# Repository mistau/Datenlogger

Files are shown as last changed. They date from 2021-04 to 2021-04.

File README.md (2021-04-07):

# Datenlogger
Flexible data logger working for many months on cheap AA batteries.

## Status
PCB back from fab, populated and tested. Extensive testroutines available in folder hwtest.
Unfortunatelly PCB rev 1.0 has two missing connections (i2c bus) which requires two ugly wires.
This is fixed in HW revision 1.1.
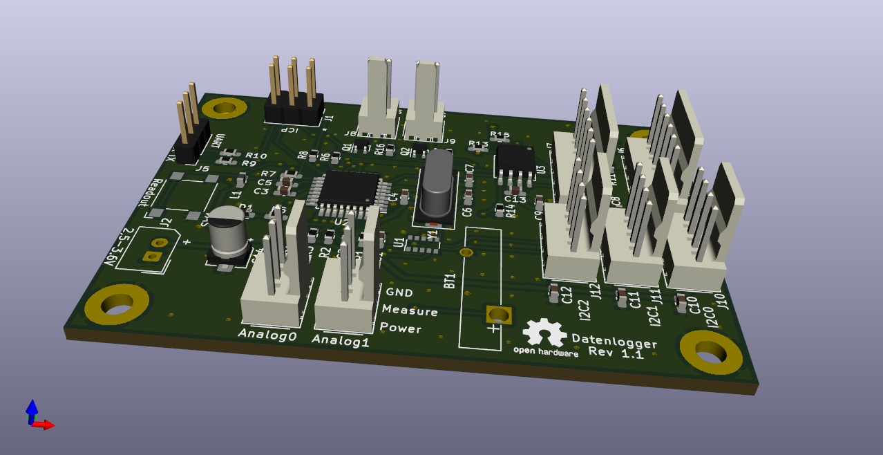
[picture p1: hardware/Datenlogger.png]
3D


## what's next
Application software for light sensor under development.

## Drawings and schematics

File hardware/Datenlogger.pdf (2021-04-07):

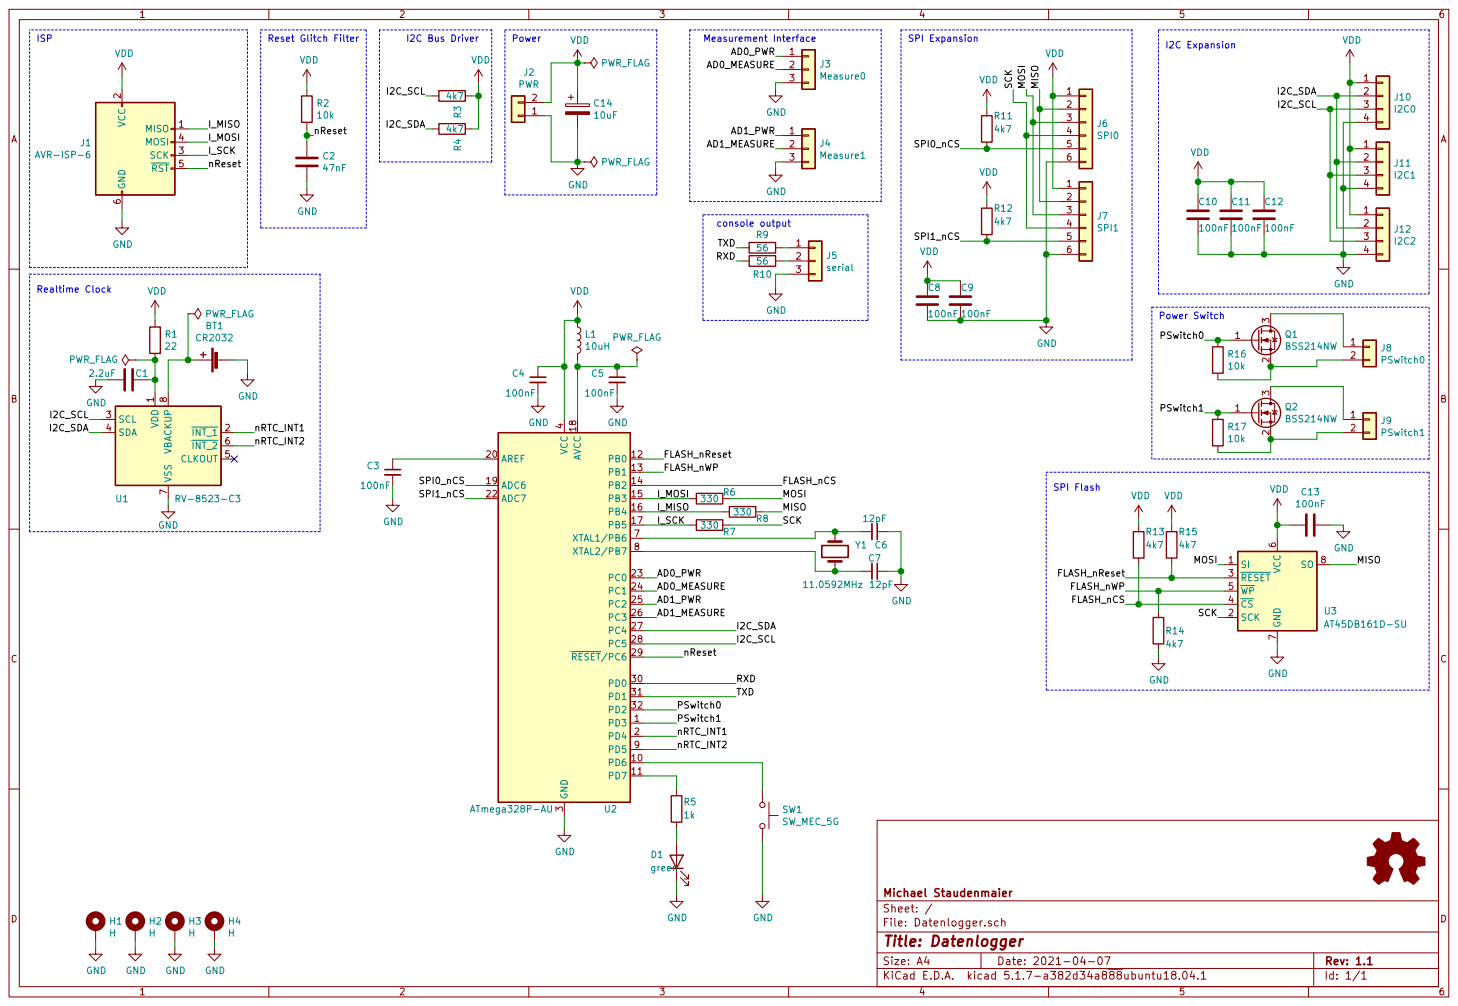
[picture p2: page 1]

2 SCK 3 MOSI 4 RST 5 GND

File: Datenlogger.sch Sheet: / Michael Staudenmaier

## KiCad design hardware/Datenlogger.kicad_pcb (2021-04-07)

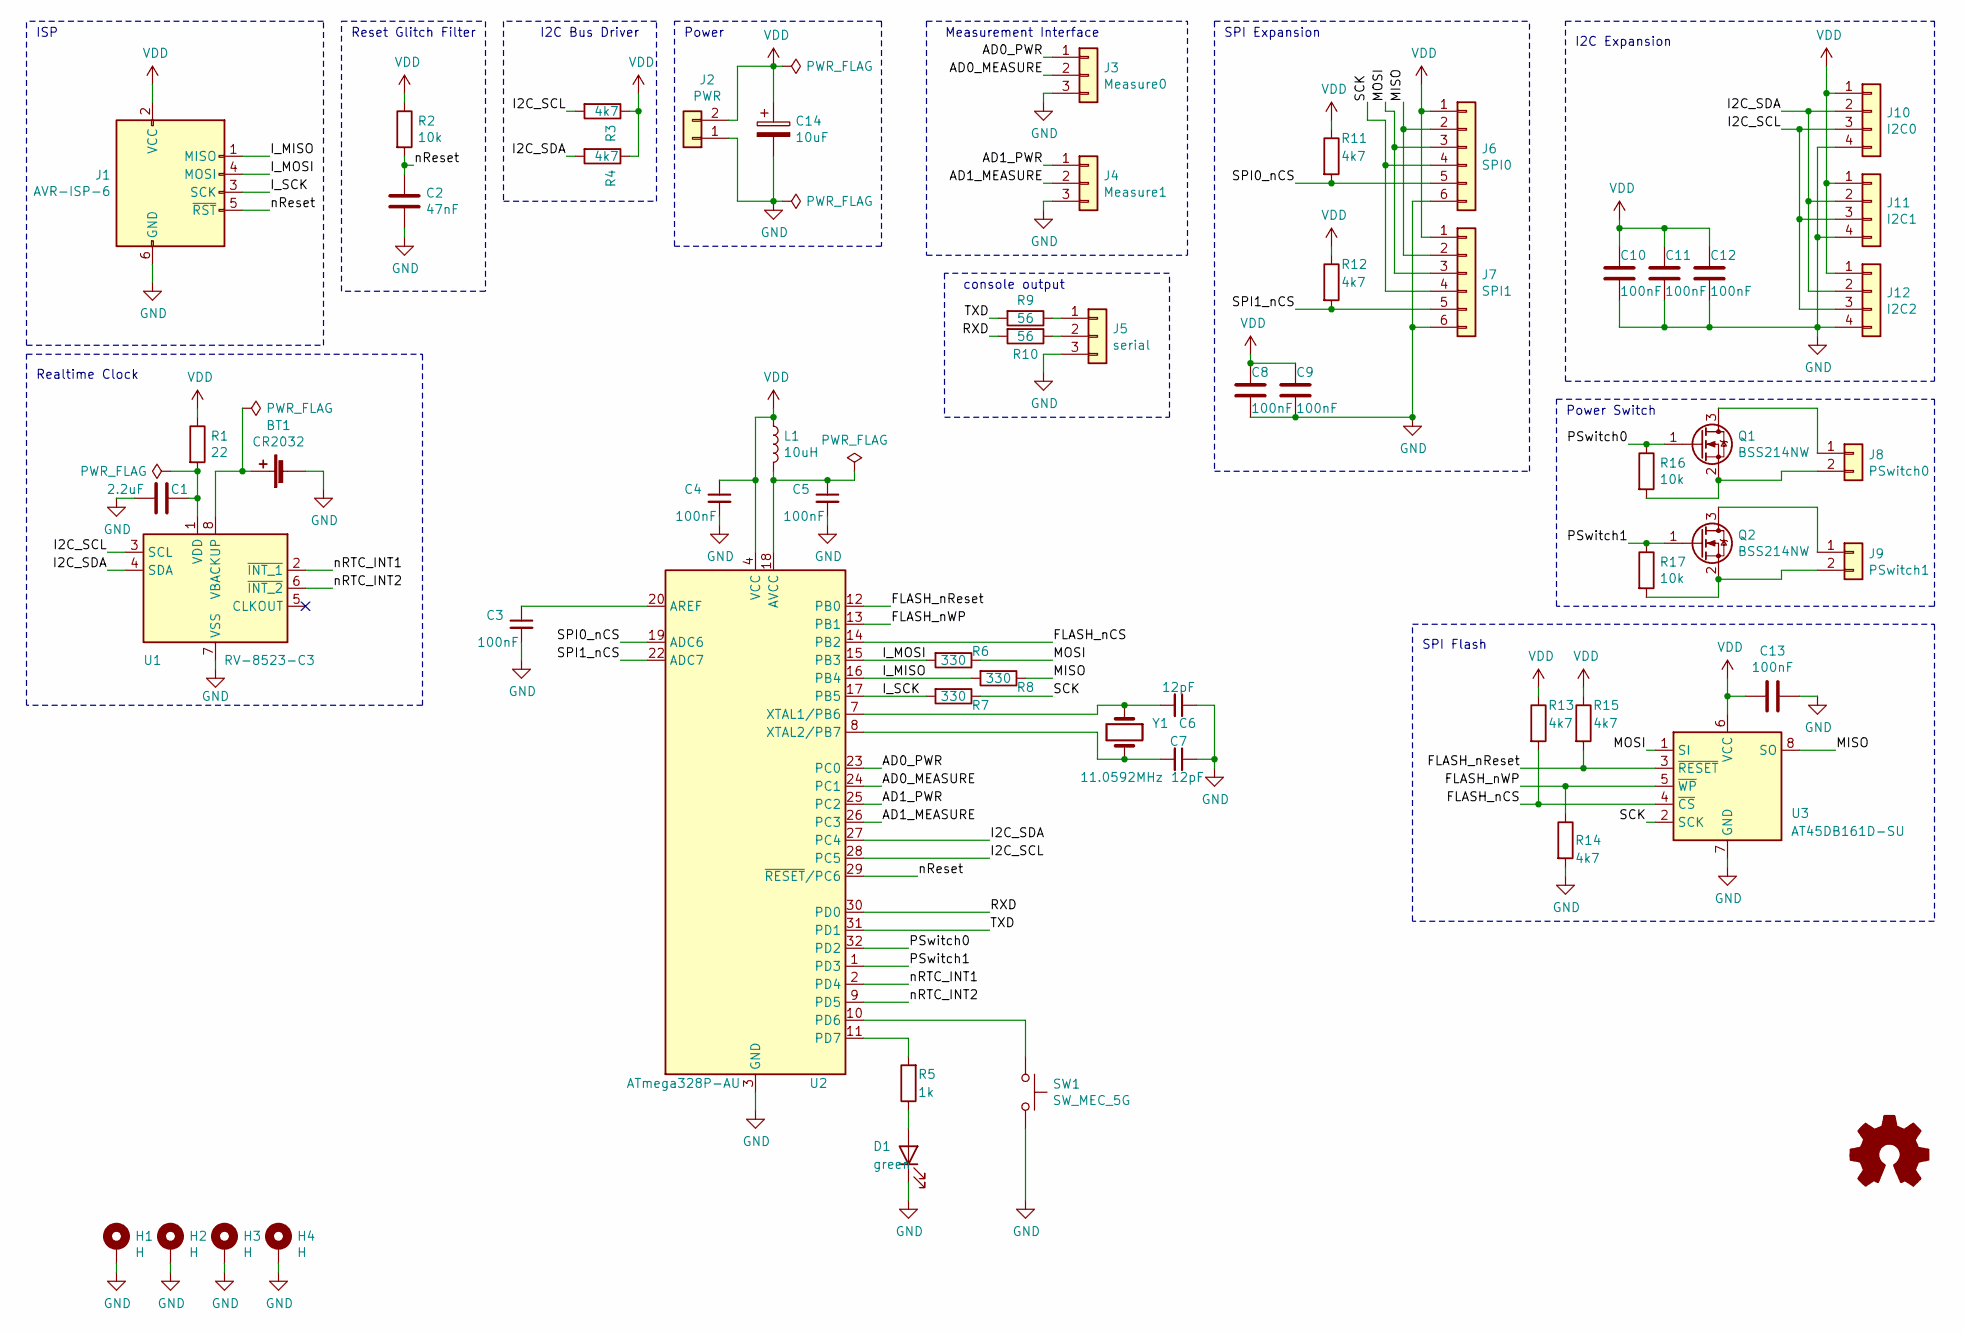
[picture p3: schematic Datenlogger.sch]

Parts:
BT1: CR2032; Battery_Panasonic_CR2032-VS1N_Vertical_CircularHoles
C1: 2.2uF; C_0603_1608Metric_Pad1.08x0.95mm_HandSolder
C2: 47nF; C_0603_1608Metric_Pad1.08x0.95mm_HandSolder
C3, C4, C5, C8, C9, C10, C11, C12, C13: 100nF; C_0603_1608Metric_Pad1.08x0.95mm_HandSolder
C6, C7: 12pF; C_0603_1608Metric_Pad1.08x0.95mm_HandSolder
C14: 10uF; CP_Elec_4x5.4
D1: green; D_0603_1608Metric_Pad1.05x0.95mm_HandSolder
H1, H2, H3, H4: H; MountingHole_3.2mm_M3_Pad_TopBottom
J1: AVR-ISP-6; PinHeader_2x03_P2.54mm_Vertical
J2: PWR; Molex_SPOX_5267-02A_1x02_P2.50mm_Vertical
J3: Measure0; Molex_KK-254_AE-6410-03A_1x03_P2.54mm_Vertical
J4: Measure1; Molex_KK-254_AE-6410-03A_1x03_P2.54mm_Vertical
J5: serial; PinHeader_1x03_P2.54mm_Vertical
J6: SPI0; Molex_KK-254_AE-6410-06A_1x06_P2.54mm_Vertical
J7: SPI1; Molex_KK-254_AE-6410-06A_1x06_P2.54mm_Vertical
J8: PSwitch0; Molex_KK-254_AE-6410-02A_1x02_P2.54mm_Vertical
J9: PSwitch1; Molex_KK-254_AE-6410-02A_1x02_P2.54mm_Vertical
J10: I2C0; Molex_KK-254_AE-6410-04A_1x04_P2.54mm_Vertical
J11: I2C1; Molex_KK-254_AE-6410-04A_1x04_P2.54mm_Vertical
J12: I2C2; Molex_KK-254_AE-6410-04A_1x04_P2.54mm_Vertical
L1: 10uH; L_0603_1608Metric_Pad1.05x0.95mm_HandSolder
Q1, Q2: BSS214NW; SOT-323_SC-70
R1: 22; R_0603_1608Metric_Pad0.98x0.95mm_HandSolder
R2, R16, R17: 10k; R_0603_1608Metric_Pad0.98x0.95mm_HandSolder
R3, R4, R11, R12, R13, R14, R15: 4k7; R_0603_1608Metric_Pad0.98x0.95mm_HandSolder
R5: 1k; R_0603_1608Metric_Pad0.98x0.95mm_HandSolder
R6, R7, R8: 330; R_0603_1608Metric_Pad0.98x0.95mm_HandSolder
R9, R10: 56; R_0603_1608Metric_Pad0.98x0.95mm_HandSolder
SW1: SW_MEC_5G; SW_SPST_Omron_B3FS-100xP
U1: RV-8523-C3; RTC_SMD_MicroCrystal_C3_2.5x3.7mm
U2: ATmega328P-AU; TQFP-32_7x7mm_P0.8mm
U3: AT45DB161D-SU; SOIC-8_5.275x5.275mm_P1.27mm
Y1: 11.0592MHz; Crystal_SMD_HC49-SD

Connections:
/AD0_MEASURE: J3.2, U2.24 (PC1)
/AD0_PWR: J3.1, U2.23 (PC0)
/AD1_MEASURE: J4.2, U2.26 (PC3)
/AD1_PWR: J4.1, U2.25 (PC2)
/FLASH_nCS: R13.2, U2.14 (PB2), U3.4 (~CS)
/FLASH_nReset: R15.2, U2.12 (PB0), U3.3 (~RESET~)
/FLASH_nWP: R14.1, U2.13 (PB1), U3.5 (~WP)
/I2C_SCL: J10.3, J11.3, J12.3, R3.2, U1.3 (SCL), U2.28 (PC5)
/I2C_SDA: J10.2, J11.2, J12.2, R4.2, U1.4 (SDA), U2.27 (PC4)
/I_MISO: J1.1 (MISO), R8.2, U2.16 (PB4)
/I_MOSI: J1.4 (MOSI), R6.2, U2.15 (PB3)
/I_SCK: J1.3 (SCK), R7.2, U2.17 (PB5)
/MISO: J6.2, J7.2, R8.1, U3.8 (SO)
/MOSI: J6.3, J7.3, R6.1, U3.1 (SI)
/PSwitch0: Q1.1 (G), R16.1, U2.32 (PD2)
/PSwitch1: Q2.1 (G), R17.1, U2.1 (PD3)
/RXD: R10.2, U2.30 (PD0)
/SCK: J6.4, J7.4, R7.1, U3.2 (SCK)
/SPI0_nCS: J6.5, R11.2, U2.19 (ADC6)
/SPI1_nCS: J7.5, R12.2, U2.22 (ADC7)
/TXD: R9.2, U2.31 (PD1)
/nRTC_INT1: U1.2 (~INT_1), U2.2 (PD4)
/nRTC_INT2: U1.6 (~INT_2), U2.9 (PD5)
/nReset: C2.1, J1.5 (~RST), R2.2, U2.29 (~RESET~/PC6)
GND: BT1.2 (-), C1.2, C2.2, C3.2, C4.2, C5.2, C6.1, C7.1, C8.2, C9.2, C10.2, C11.2, C12.2, C13.1, C14.2, D1.1 (K), H1.1, H2.1, H3.1, H4.1, J1.6 (GND), J2.1, J3.3, J4.3, J5.3, J6.6, J7.6, J10.4, J11.4, J12.4, R14.2, SW1.3 (B), SW1.4 (B), U1.7 (VSS), U2.3 (GND), U2.5 (GND), U2.21 (GND), U3.7 (GND)
unnamed: BT1.1 (+), U1.8 (VBACKUP)
unnamed: C1.1, R1.2, U1.1 (VDD)
unnamed: C3.1, U2.20 (AREF)
unnamed: C5.1, L1.2, U2.18 (AVCC)
unnamed: C6.2, U2.7 (XTAL1/PB6), Y1.1
unnamed: C7.2, U2.8 (XTAL2/PB7), Y1.2
unnamed: D1.2 (A), R5.1
unnamed: J5.1, R9.1
unnamed: J5.2, R10.1
unnamed: J8.1, Q1.3 (D)
unnamed: J8.2, Q1.2 (S), R16.2
unnamed: J9.1, Q2.3 (D)
unnamed: J9.2, Q2.2 (S), R17.2
unnamed: R5.2, U2.11 (PD7)
unnamed: SW1.1 (A), SW1.2 (A), U2.10 (PD6)
VDD: C4.1, C8.1, C9.1, C10.1, C11.1, C12.1, C13.2, C14.1, J1.2 (VCC), J2.2, J6.1, J7.1, J10.1, J11.1, J12.1, L1.1, R1.1, R2.1, R3.1, R4.1, R11.1, R12.1, R13.1, R15.1, U2.4 (VCC), U2.6 (VCC), U3.6 (VCC)

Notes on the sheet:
I2C Bus Driver
ISP
Reset Glitch Filter
Realtime Clock
I2C Expansion
SPI Flash
Power Switch
SPI Expansion
Power
Measurement Interface
console output

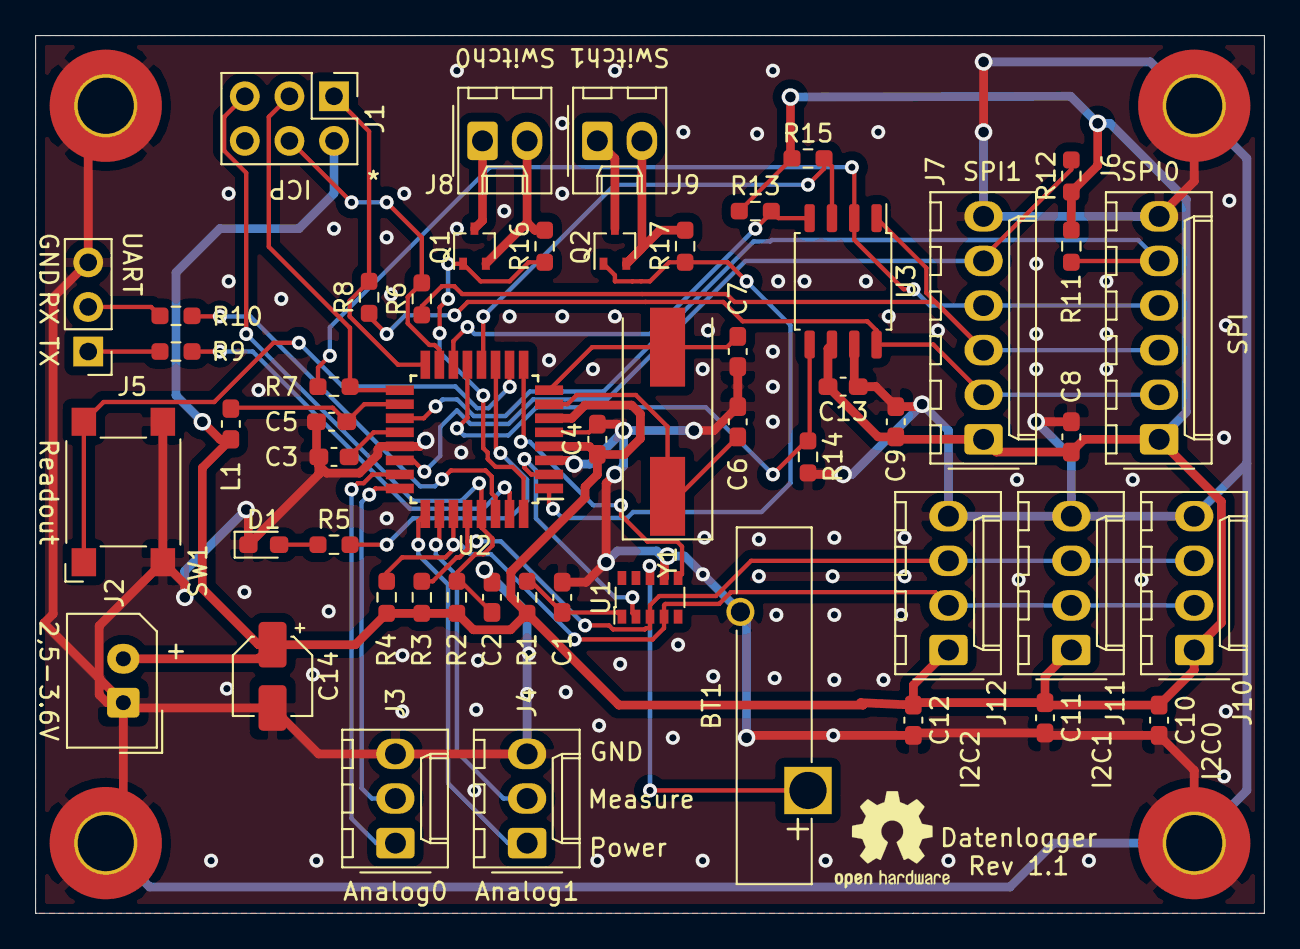
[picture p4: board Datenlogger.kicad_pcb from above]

Board: 2 copper layers, 70.0 x 50.0 mm, 57 parts (0 on the bottom side), 41 nets.

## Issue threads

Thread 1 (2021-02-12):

Input voltage limited to 2.3-3.6V

mistau, 2021-02-12:
Due to the limits of the flash device used AT45BD* the voltage range has to be limited 2.3-3.6V.
First PCBs have a range from 2.5-5V written on them in front of the power plug.

Closed 2021-02-12.

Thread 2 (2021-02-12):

R1 is way too high

mistau, 2021-02-12:
to reduce the ramp down slope for the RTC RV-8523-C3 there was the resistor R1 added to the power supply. Thinking about this some more this is way too high and should be replaced by a way smaller one.
https://github.com/watterott/RTC-Breakout/blob/master/hardware/RV8523-RTC-Breakout_v10.pdf uses 22Ohm with 2.2uF capacitor.

Closed 2021-02-12.

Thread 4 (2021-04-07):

RTC power ramp down too steep

mistau, 2021-04-07:
due to wrong combination C1 / R1 the RTC might fail when switching over to battery.

Closed 2021-04-07.

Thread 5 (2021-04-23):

jumper for RTC battery

mistau, 2021-04-23:
to recover in case the RTC hangs (which happened already quite a few times due to buggy programming I assume) a jumper to disconnect the RTC from the battery would be helpful. Should be bypassed by a 0Ohm resistor.

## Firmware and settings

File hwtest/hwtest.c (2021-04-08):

/*
 * -------------------------------------------------------------------------
 * HW Test Routine
 * Datensammler
 * Version 0.1 fuer HW Rev 1.0
 *
 * Copyright 2021 - Michael Staudenmaier
 * -------------------------------------------------------------------------
 */

#include <stdio.h>
#include <stdbool.h>
#include <avr/io.h>
#include <avr/interrupt.h>
#include <avr/sleep.h>
#include <avr/wdt.h>
#include <avr/pgmspace.h>
#include <util/delay.h>
#include <stdint.h>
#include <string.h>

#include "i2cmaster.h"
#include "spi_master.h"

#include "flash.h"
#include "rv8523.h"
#include "rv8523_regs.h"

#include "hwconfig.h"


/* =================================================================
   settings
   ================================================================= */

#define UART_OUTPUT(x)   x    // define this to x to get output, otherwise to nothing

#define TEST_LED                   1
#define TEST_UART                  1
#define TEST_RTC                   1
#define TEST_RTC_IRQ               1
#define TEST_FLASH                 1
#define TEST_PUSHBUTTON_IRQ        1

/* =================================================================
   Deklarationen
   ================================================================= */

static int uart_putchar(char c, FILE *stream);
static int uart_getchar(FILE *stream);
static FILE mystdout = FDEV_SETUP_STREAM(uart_putchar, uart_getchar, _FDEV_SETUP_RW);

static volatile uint8_t rtcint_counter = 0;
static volatile uint8_t buttonint_counter = 0;


/* =================================================================
   ISR functions
   ================================================================= */

// ISR for INT1 from RTC -> AtMega328P PD4 = PCINT20
// ISR für Pushbutton -> ATMEGA328P PD6 = PCINT22
ISR(PCINT2_vect)
{

    /* handler for RTC wakeup interrupt */
    if(!(PIND & _BV(RTCINT1))){ // triggered by the RTC
        PORTD |= _BV(LED_STATE);
        rv8523_clearAlarmFlag();
        rv8523_setAlarmMinute(false, 0, true);
        ++rtcint_counter;
        // wait until IRQ line is back up!
        while(!(PIND & _BV(RTCINT1)))
            ;
        PORTD &= ~_BV(LED_STATE);
    }

    /* handler for button pressed interrupt */
    if(!(PIND & _BV(BUTTON))){ // triggered by the button
        do{
            _delay_ms(10);
        }while(!(PIND & _BV(BUTTON)));
        _delay_ms(10);
        ++buttonint_counter;
    }
}

// ISR for wakeup-key
#if(0)
ISR(INT0_vect)
{
    LED_PORT = _BV(LED_STATUS);
    _delay_ms(200);
    LED_PORT &= ~_BV(LED_STATUS);
}
#endif

/* =================================================================
   Initialisierung des Chips
   
   In: nix
   Out: nix
   ================================================================= */
static void ioinit(void)
{
    // set baud rate - 1156200
    const unsigned int ubrr = 0xb;
    UBRR0H = (unsigned char) (ubrr>>8);
    UBRR0L = (unsigned char) ubrr;

    UCSR0A |= (1<<U2X0);

    /* set frame format 8N1 */
    UCSR0C = (0<<USBS0) | (3<<UCSZ00);

    /* enable receiver and transmitter */
    UCSR0B |= (1<<RXEN0) | (1<<TXEN0);
        
    stdin = stdout = &mystdout; //Required for printf init
}


static int uart_putchar(char c, FILE *stream)
{
    if (c == '\n') uart_putchar('\r', stream);
    
    loop_until_bit_is_set(UCSR0A, UDRE0);
    UDR0 = c;
    return 0;
}

static int uart_getchar(FILE *stream)
{
    uint8_t data;
    loop_until_bit_is_set(UCSR0A, RXC0);
    data = UDR0;

    // echo output
    uart_putchar(data, stream);

    return data;
}


/**
 * Initialize processor
 * Set status
 * Endless loop putting the processor in sleep mode
 */
int main (void)
{
    int i;
    uint8_t val;
    uint8_t errors = 0;

    uint8_t year = 0x21;
    uint8_t month= 0x02;
    uint8_t weekday = 0x05;
    uint8_t day = 0x19;
    uint8_t hour = 0x23;
    uint8_t min = 0x50;
    uint8_t sec = 0x00;
    uint8_t buffer[512];

    ioinit();
    i2c_init();
    spi_masterInit();
    
    // set time once
#if(1)
    rv8523_coldInit();
    rv8523_setDateTime24(year, month, day, weekday, hour, min, sec, true);
#else
    rv8523_init();
#endif
    
    // configure GPIO
    DDRD = _BV(LED_STATE);             // output: LED, - input: INT1, Pushbutton
    PORTD = _BV(BUTTON) | _BV(RTCINT1); // pullup for RTC:INT1 and Pushbutton

    //DDRB &= ~0x07;    // all control signals to input (i.e. pull-up/pull-down drives them inactive!)
    //PORTB |= 0x02;    // nReset=0 nWP=1 nCS=0

    PORTB |= 0x05;    // nReset=1 nWP=0 nCS=1
    DDRB |= 0x07;    // all control signals to output
    
    // configure interrupt settings
    cli();
    PCMSK2 = _BV(PCINT20) | _BV(PCINT22);
    PCICR = _BV(PCIE2);

    printf_P(PSTR("\n\n*Datenlogger Rev 1.0 Board HW test\n"));

    while(1){

#if(TEST_LED)
        printf_P(PSTR("Testcase 1: observe LED test pattern on board!\n"));
        for(i=0; i<3; ++i){
            PORTD |= _BV(LED_STATE);
            _delay_ms(500);
            PORTD &= ~_BV(LED_STATE);
            _delay_ms(500);
        }
#endif
       
#if(TEST_UART)    
        printf_P(PSTR("Testcase 2: press 'a' in the terminal. "));
        scanf("%c", &val);
        if(val=='a')
            printf_P(PSTR("pass\n"));
        else{
            printf_P(PSTR("FAIL\n"));
            ++errors;
        } 
#endif
        
#if(TEST_RTC)
        printf_P(PSTR("Testcase 3: check RTC via I2C."));
        /* let's read the current time */
        uint8_t year, month, day, weekday, hour, min, sec;
        rv8523_getDateTime24(&year, &month, &day, &weekday,
                             &hour, &min, &sec, false);
        bool bat = false;
        printf_P(PSTR("  %02d:%02d:%02d %02d.%02d.20%02d (BattLow=%s)\n"),
                 hour, min, sec, day, month, year, bat? "true":"false");
#endif

#if(TEST_RTC_IRQ)
        printf_P(PSTR("Testcase 4: check interrupts triggered by RTC (alarm min=%02d) "), (min+1)%60);
        while(!(PIND & _BV(RTCINT1))){
            printf_P(PSTR("Failed\n*** Warning: RTCIN0 active - trying to de-assert IRQ\n"));
            rv8523_clearAlarmFlag();
            PCIFR |= _BV(PCIF2); // clear IRQ request as well
            ++errors;
        }

        if(PIND & _BV(RTCINT1)){  // IRQ line is high
            uint8_t vals[0x14];
            // PCIFR |= _BV(PCIF2); // clear IRQ request as well
            rv8523_setAlarmMinute(true, min+1, false);
            rv8523_setAlarmIrq(true);
            if(!(PIND & _BV(RTCINT1))){
                printf("aarrgg - low again!\n");
            }

            rtcint_counter = 0;
            sei(); // is that required?
            while(rtcint_counter==0)
                ;
            cli();
            printf_P(PSTR("Passed\n"));
        }
#endif

#if(TEST_FLASH)
        printf_P(PSTR("Testcase 5: read ID of Flash device. "));
        uint8_t buf[5];
        uint8_t buf2[2];
            
        //flash_init();  // trigger a reset to start with
        // spi_masterInit();
        flash_get_id(buf);
        flash_get_status(buf2);
        printf_P(PSTR("ID(%02x %02x %02x %02x %02x) STATUS(%02x %02x). "), buf[0], buf[1], buf[2], buf[3], buf[4], buf2[0], buf2[1]);
        if((buf[0]==0x1f)
           && (buf[1]==0x27)
           && (buf[2]==0x01))
            printf_P(PSTR("ok\n"));
        else{
            printf_P(PSTR("FAIL\n"));
            ++errors;
        }
        if(buf2[0] & 0x1){
            printf_P(PSTR("            flash configured with 512bytes/sector\n"));
        }else{
            printf_P(PSTR("            flash configured with 528bytes/sector\n"));
            printf_P(PSTR("            ->we'll fix that for you. "));
            flash_conf_power2_size();
            flash_get_status(buf2);
            if(buf2[0]&0x01){
                printf_P(PSTR("ok\n"));
            }else{
                printf_P(PSTR("FAIL\n"));
                ++errors;
            }     
        }

        printf_P(PSTR("Testcase 6: write page to flash.\n"));
        int i=8000;
        buffer[0] = (i >>8) & 0xff;
        buffer[1] = i & 0xff;
        flash_write_page(i, buffer);
        flash_enter_ultradeep_powerdown();
        _delay_ms(1000);
        flash_resume_ultradeep_powerdown();        

        printf_P(PSTR("Testcase 7: read page from flash. "));
        flash_read_page(buffer, 8000);
        if((buffer[0] == ((i >>8) & 0xff)) &&
           (buffer[1] == (i & 0xff))){
            printf_P(PSTR("ok\n"));            
        }else{
            printf_P(PSTR("FAIL\n"));
            ++errors;
        }
#endif

#if(TEST_PUSHBUTTON_IRQ)        
        printf_P(PSTR("Testcase 8: check interrupts triggered by pushbutton "));
        if(!(PIND & _BV(BUTTON))){
            printf_P(PSTR("Failed\n*** Error: pin not pulled high!\n"));
            ++errors;
        }else{
            buttonint_counter = 0;
            sei();
            while(!buttonint_counter)
                ;
            cli();
            printf_P(PSTR("Passed\n"));        
        }
#endif

        UART_OUTPUT(printf_P(PSTR("\n*****************Summary %d errors ******************\n\n"), errors));
    }

    return (0);
}

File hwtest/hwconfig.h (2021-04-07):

/*
 * -------------------------------------------------------------------------
 * Controller fuer den Tauben Datenlogger
 * Version 0.1 fuer HW Rev 1.0
 * hardware definitionen
 * -------------------------------------------------------------------------
 *  M.Staudenmaier
 */

#ifndef _HWCONFIG_H_
#define _HWCONFIG_H_

/* the LEDs connections */
#define LED_STATE        PD7       /**< on-pcb status LED */

/* Input Keys */
#define BUTTON           PD6

/* Interrupt Inputs */
#define RTCINT1          PD4
#define RTCINT2          PD5

/* outputs */
#define PSWITCH0         PD2
#define PSWITCH1         PD3

/* connections to flash device */
#define FLASH_DDR    DDRB
#define FLASH_NRESET PB0
#define FLASH_NWP    PB1
#define FLASH_NCS    PB2

#endif

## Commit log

2021-01-26 initial hardware done.
    [Datenlogger.kicad_pcb, Datenlogger.sch]
2021-01-29 Updated oscilator to be suited for standard UART baudrates.
    [Datenlogger.kicad_pcb, Datenlogger.sch]
2021-02-12 fix: Minor fixes to the hardware
    Corrected text on allowed voltages to 2.6V-3.6V caused by the limits of the flash device.
    Modified value of R1 to 56Ohm as the original was clearly way too high.
    fixes #1
    fixes #2
    [Datenlogger.kicad_pcb, Datenlogger.sch]
2021-04-07 Fundamental HW Fix, added testsuite
    * fix #3 missing I2C connections
    * fix #4 different components for R1/C1 to ensure switch-over to battery
    * add extensive testsuite hwtest used to verify the HW.
    [Datenlogger.kicad_pcb, Datenlogger.sch]
2021-04-08 Cleaned up flash device test
    All test routines are enabled now to allow a test
    of the key board functionality.
2021-04-08 Enable battery in RTC.
